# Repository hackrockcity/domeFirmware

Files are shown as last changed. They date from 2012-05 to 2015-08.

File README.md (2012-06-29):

domeFirmware
============

LED driver for the dome project. Each board can control 8 LED strips, each of which is up to 5m long.

## python_host
A python server that listens on UDP for a serialized 24bit RGB stream (8 bits per channel) that describes a 24 wide by 160 high image from top left to bottom right. (Yo dawg your aspect ratio is wrong). The data is then output to a Teensy over a high-speed serial port.

Usage:

```python
    python domelistener.py
```

## board
PCB design for the breakout board

## firmware
Firmware that should be compiled using the Makefile, then uploaded to the teensy using the teensy utility.

## mounting hardware
3d models for whatever mounts.

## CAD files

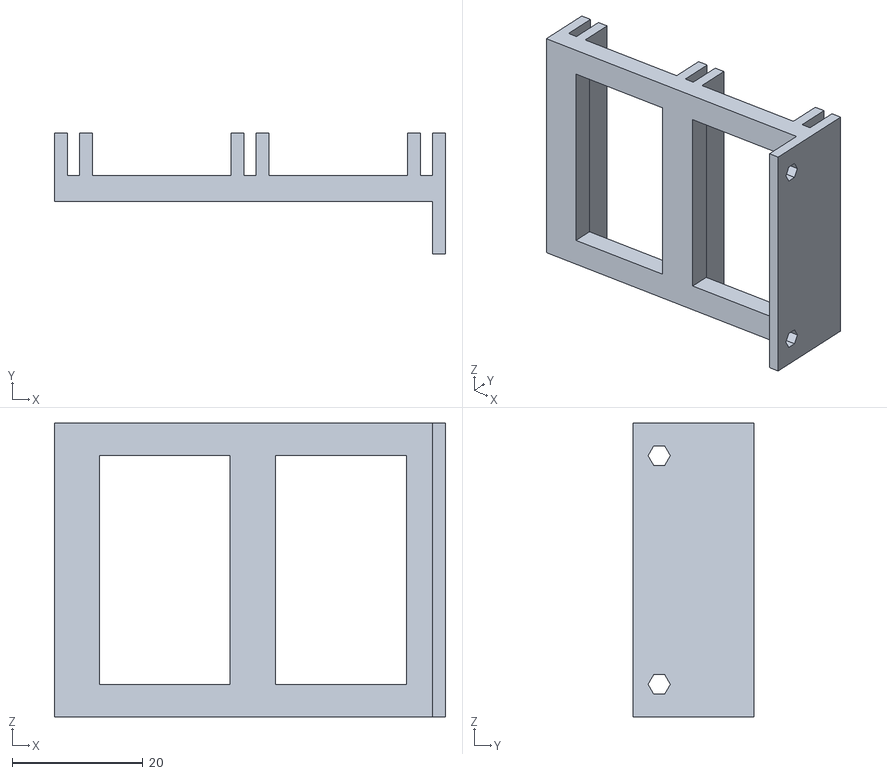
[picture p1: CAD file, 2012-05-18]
mounting hardware/mount.stl
59.9 x 18.5 x 45.0

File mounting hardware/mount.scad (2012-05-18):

board_width = 45;
board_thickness = 1.85;
board_separation = 27;

platform_thickness = 2;

module ledge() {
  union() {
    cube(size = [6.5,platform_thickness,board_width]);
    translate([0,platform_thickness+board_thickness,0])
      cube(size = [6.5,platform_thickness,board_width]);

//    translate([0,platform_thickness+1,0])
//      rotate(a=[90,0,0])
//        translate([6,3,0])
//          cylinder(h=platform_thickness+1,r=1.3);

//    translate([0,platform_thickness+1,board_width-6])
//      rotate(a=[90,0,0])
//        translate([6,3,0])
//          cylinder(h=platform_thickness+1,r=1.3);
  }
}

module mount() {
  translate([-8,0,0]) {

    difference() {
      cube(size=[8,platform_thickness,board_width]);

      translate([0,platform_thickness+.25,0])
        rotate(a=[90,0,0])
          translate([4,5,0])
            cylinder(h=platform_thickness+.5,r=1.7);

      translate([0,platform_thickness+.25,board_width-6])
        rotate(a=[90,0,0])
          translate([4,1,0])
            cylinder(h=platform_thickness+.5,r=1.7);
    }
  }
}

difference() {
  cube(size = [4,2*board_separation+platform_thickness*2+board_thickness,board_width]);
  translate([-.5,6,5])
    cube(size=[5,20,board_width-10]);
  translate([-.5,6+board_separation,5])
    cube(size=[5,20,board_width-10]);
}

mount();


translate([4,0,0])
  ledge();
translate([4,board_separation,0])
  ledge();
translate([4,board_separation*2,0])
  ledge();

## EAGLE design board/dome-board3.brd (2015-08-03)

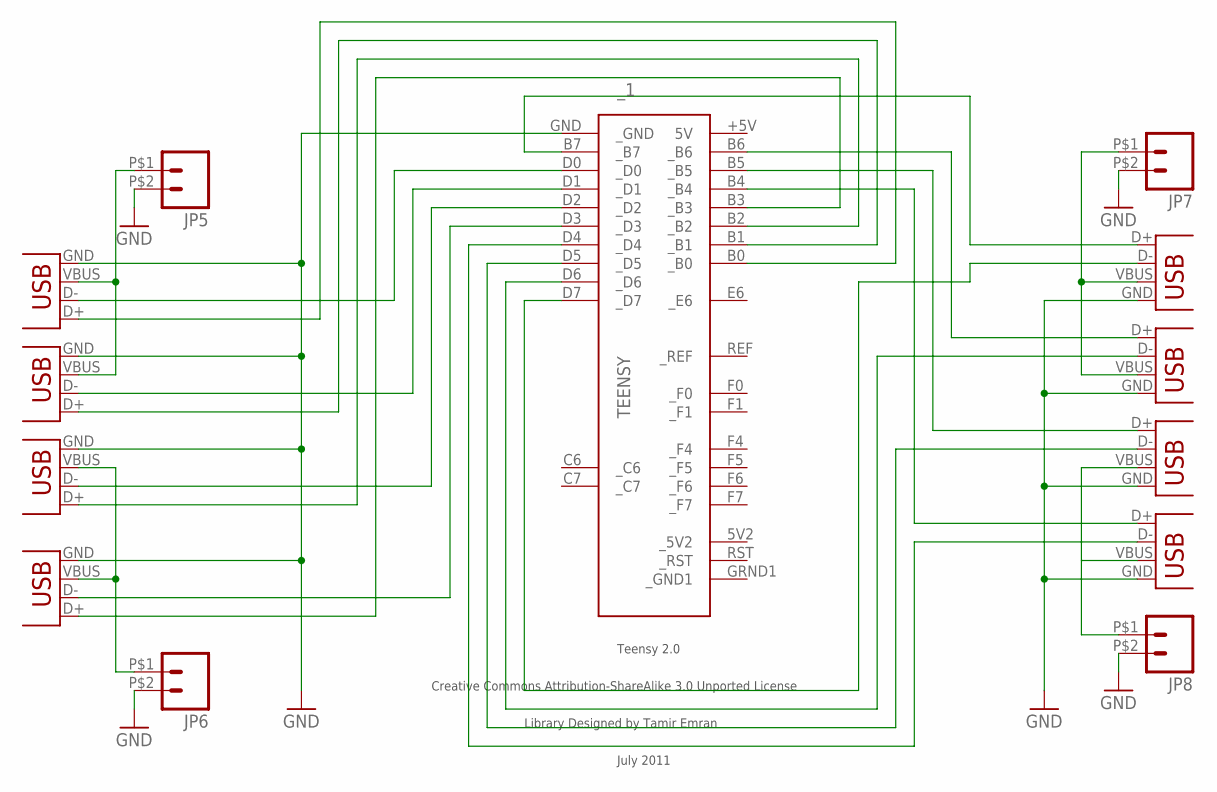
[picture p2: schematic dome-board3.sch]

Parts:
JP5, JP6, JP7, JP8: M026.35MM; SCREWTERMINAL-6.35MM-2
USB1, USB2, USB3, USB4, USB5, USB6, USB7, USB8: USB; USBA
_1: TEENSY

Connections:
GND: JP5.P$2 (2), JP6.P$2 (2), JP7.P$2 (2), JP8.P$2 (2), USB1.GND, USB2.GND, USB3.GND, USB4.GND, USB5.GND, USB6.GND, USB7.GND, USB8.GND, _1.GND (_GND)
unnamed: USB1.D+, _1.B0 (_B0)
unnamed: USB2.D+, _1.B1 (_B1)
unnamed: USB3.D+, _1.B2 (_B2)
unnamed: USB4.D+, _1.B3 (_B3)
unnamed: USB5.D+, _1.B4 (_B4)
unnamed: USB6.D+, _1.B5 (_B5)
unnamed: USB7.D+, _1.B6 (_B6)
unnamed: USB1.D-, _1.D0 (_D0)
unnamed: USB2.D-, _1.D1 (_D1)
unnamed: USB3.D-, _1.D2 (_D2)
unnamed: USB4.D-, _1.D3 (_D3)
unnamed: USB5.D-, _1.D4 (_D4)
unnamed: USB6.D-, _1.D5 (_D5)
unnamed: USB7.D-, _1.D6 (_D6)
unnamed: USB8.D-, _1.D7 (_D7)
unnamed: USB8.D+, _1.B7 (_B7)
VCC1: JP5.P$1 (1), USB1.VBUS, USB2.VBUS
VCC2: JP7.P$1 (1), USB7.VBUS, USB8.VBUS
VCC3: JP6.P$1 (1), USB3.VBUS, USB4.VBUS
VCC4: JP8.P$1 (1), USB5.VBUS, USB6.VBUS

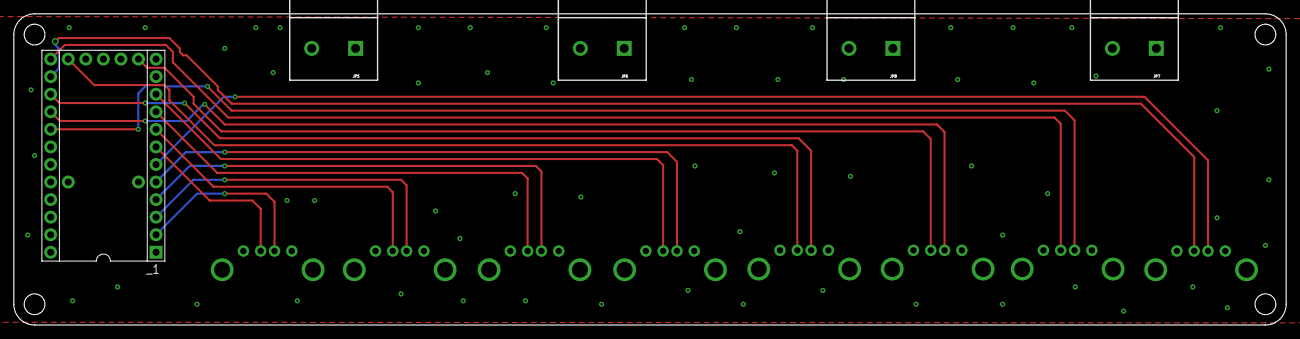
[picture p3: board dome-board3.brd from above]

Board: 2 copper layers, 184.0 x 45.0 mm, 13 parts (0 on the bottom side), 21 nets.

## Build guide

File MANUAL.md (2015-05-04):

# DomeStar Users Manual

## Introduction

This document serves as a general purpose overview for DomeStar.  It will walk through construction, the various software components and protocols, and applications that have been developed for the project.

## Setup

### Requirements

To install DomeStar you will need a somewhat recent MacBook Pro or Linux laptop with a decent amount of horse power.  You will needed the following software:

* Git
* GCC build tools
* [domeFirmware](https://github.com/hackrockcity/domeFirmware)
* [Processing](http://www.processing.org)
* [Processing UDP library](http://www.ubaa.net/shared/processing/udp/)
* [Processing OSC Library](http://www.sojamo.de/libraries/oscP5/)
* [domeTransmitter](https://github.com/hackrockcity/domeTransmitter)
* DarwiinRemoteOSC or something similar (WiiMote -> Open Sound Control)

### Components

DomeStar is made up of the following components

* 5 x Controller Boxes
* 5 x Wood Strip Mounts
* 40 x 5m LED strips
* Power Supply
* 5 x DC power cables
* USB hub
* USB extension cables
* Lot of zip ties

### Physical construction

Top of DomeStar

To build DomeStar first build a dome.  The dome should be at least 8ft in diameter, but preferably bigger.  Only 2V domes have been used, it is unknown if other configurations will work.

At the top of the dome zip tie the five controller boxes with the JST connector wires facing out from the center of the dome.  Make sure the lids of the boxes face down so they can be accessed.

At the very center of the dome zip tie the USB hub down.  Connect each box to the USB hub.  Plug a USB cable into the hub and zip tie it down the side of the dome as far as it will go.  Then connect the USB extension and continue down to the ground and to the laptop.

Zip tie the DC power cables up the same path the USB extension took and plug one cable into each box.  The connector should push in, turn and click to lock.  Some of the connectors are damaged and take some finessing, it would be worthwhile to try it on the ground before doing it on the top of a dome.

Zip tie the wood strip mounts across two poles of the dome so that they create a bridge just below the controller boxes.  Route a zip tie through each pair of slots in the mount and close but leave loose enough to guide an LED strip through.

Zip tie the LED strips around the sides of the dome, spacing them evently.  Eight strips should connect to each box.  Make sure that the strips are tied such that the strain on the JST connector is minimized.  There should be some slack at the top.  See the 
picture at the top.

Connect the DC power cables to the power supply and connect the power supply to a AC power source like a generator or the grid.

### Configuration

You should be ready to power on DomeStar and configure it.  First do a quick on and off test of the power supply as a smoke test. If something smokes, STOP and contact a DomeStar Service Technician immediately.

Once the USB cable has been connected to the notebook you should see additional USB devices show up in /dev.  Open a terminal and take a look:

```
macbook$ ls /dev/cu.*

/dev/cu.Bluetooth-Port  /dev/cu.Bluetooth-Modem /dev/cu.JustinsJAMBOX-SPPDev-1
/dev/cu.usbmodem00001   /dev/cu.usbmodem10001   /dev/cu.usbmodem20001
/dev/cu.usbmodem30001   /dev/cu.usbmodem40001
```

You should see 5 devices matching "cu.usbmodemNNNNN".  The numbers are usually but not always five digits.  These are the controler boxes.  Now go to the domeFirmware/c++_host directory and edit run_osx.sh.

```
#!/bin/bash
./host 160 40 /dev/cu.usbmodem00001 0 /dev/cu.usbmodem10001 8 /dev/cu.usbmodem20001 16 /dev/cu.usbmodem30001 24 /dev/cu.usbmodem40001 32
```

The syntax of the host program is:

```
./host [height] [width] [device] [offset]...[device] [offset]
```

For now just replace the usbmodem devices with ones that came up on your notebook if they are different.  You will need to reorder them in the next step.

Run the script to start the listener

```
./run_osx.sh
```

Now start Processing and open domeTransmitter.  You will need to make some changes to the code to get it ready for configuration.  In the main domeTransmitter.pde find the section near the top that lists all the enabled routines, comment all but TestPattern.

``` Java
public Routine[] enabledRoutines = new Routine[] {
    new TestPattern(true)
    //new Configulate(),
    //new TestPattern(false),
    //new Waves(),
    //new WarpSpeedMrSulu(),
    //new Warp(),
    //new TrialOfZod(),
    //new Seizure(),
    //new RainbowColors(),
    //new RGBRoutine(),
    //new Pong(),
    //new Greetz(),
    //new FFTDemo(),
    //new DropTheBomb(),
    //new ColorDrop(),
    //new Chase(),
    //new Bursts(),
    //new Animator("anim-nyancat",1,.5,0,0,0),
};
```

Run the Processing sketch and hopefully you should see strips turning on and off in a seemingly random order.  If so, YAY IT IS WORKING!

Now turn on the Configulate routine.

``` Java
public Routine[] enabledRoutines = new Routine[] {
    new Configulate()
    //new TestPattern(true),
    //new TestPattern(false),
    //new Waves(),
    //new WarpSpeedMrSulu(),
    //new Warp(),
    //new TrialOfZod(),
    //new Seizure(),
    //new RainbowColors(),
    //new RGBRoutine(),
    //new Pong(),
    //new Greetz(),
    //new FFTDemo(),
    //new DropTheBomb(),
    //new ColorDrop(),
    //new Chase(),
    //new Bursts(),
    //new Animator("anim-nyancat",1,.5,0,0,0),
};
```

Run the sketch again.  You should see one strip colored blue.  Use the left and right arrows to move around the dome, it should seem to go in slightly random order. Some newer strips will actually be green, they have their green and blue colors swapped.

Move around to any starting point you find reasonable.  Press space, the strip will turn light blue and another strip will turn the previous deep blue.  Move the left and right arrows until the strip to the right of the light blue one is lit.  If it's green press down to swap green and blue, press up to undo the swap.  Press space and that strip will turn light blue.  Repeat this process until you've gone through the whole dome.  

Once completed press "s" and you should see some code show up in the Processing debug console.  Copy/paste this code into the Config class replacing the STRIP_LOOKUP and SWAP_LOOKUP sections.

Now re-enable the TestPattern routine and you should see the strips going in order around the dome.

### Running DomeStar

Now that you have everything configured you can set the FRAMERATE back to 30 and comment out the TestPattern and uncomment the other modes in enabledModes.  You're ready to run DomeStar! 

You'll want to test out the WiiMote controls next.  We've used DarwiinOSC in the past, but it can be a pain to get working on newer versions of OSX. 

### Running DomeStar.us (EXPERIMENTAL)

DomeStar.us is an attempt to allow people to control DomeStar using their smartphone. It uses a web app hosted at [domestar.us](http://www.domestar.us) that takes the phone's orientation data and sends it to the dome using WebSockets.  If DomeStar and the phone are on the same WiFi network it will do this using a direct connection, otherwise it will send via a proxy on domestar.us.

   

There are four "totems" that need to be placed in the dome at about eye level.  The totems are a rocket, a beer mug, a squirrel and a globe.  These allow the user to calibrate their phone so that its orientation data lines up with the dome.  Each totem should be placed 90 degrees from the previous one so that the "north", "south", "east" and "west" points in the dome are covered.  These points don't need to coordinate with actual north, south, east or west.  The order of the totems should be: rocket, beer, squirrel, and then globe.

To run DomeStar in this mode, first get [DomeWebProxy](https://github.com/hackrockcity/DomeWebProxy).  Edit the Config class and paste in the appropriate STRIP_LOOKUP and SWAP_LOOKUP lines from domeTransmitter.  Run the sketch and it should connect to the domestar.us website.  If you see lots of connection errors in the Processing error console, contact Justin and have him restart the domestar proxy.

Now connect to domestar.us website using your smartphone.  Go through the calibration  routine, pointing at each totem and pressing the button.  Then tap a color swatch and use your phone like a brush.  The part of the dome you're pointing at *should* light up.

### Creating your own Routines

If you're ready to start making your own DomeStar routines go and grab [BlinkeyDomeSimulator](https://github.com/hackrockcity/BlinkeyDomeSimulator).  This sketch is a virtual version of DomeStar.  Run it and then run domeTransmitter and you should see the routines on the virtual DomeStar.  Now add a new class to domeTransmitter.

``` Java
class MyRoutine extends Routine {
  
  public MyRoutine() {
  }
  
  void draw() {
    draw.background(primaryColor);
  }
}
```

The D-Pad on the WiiMote changes the value of primaryColor, secondaryColor and teriaryColor so you should try to incorporate those into your routine.  You can also use the controller object to get the accelerometer data from the WiiMote.  Look at routines like TrialOfZod to get an idea of how that works.  Add your routine to the enabledRoutines array and run it.

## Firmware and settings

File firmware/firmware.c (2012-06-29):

/* Simple example for Teensy USB Development Board
 * http://www.pjrc.com/teensy/
 * Copyright (c) 2008 PJRC.COM, LLC
 * 
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
 * THE SOFTWARE IS PROVIDED "AS IS", WITHOUT WARRANTY OF ANY KIND, EXPRESS OR
 * IMPLIED, INCLUDING BUT NOT LIMITED TO THE WARRANTIES OF MERCHANTABILITY,
 * FITNESS FOR A PARTICULAR PURPOSE AND NONINFRINGEMENT. IN NO EVENT SHALL THE
 * AUTHORS OR COPYRIGHT HOLDERS BE LIABLE FOR ANY CLAIM, DAMAGES OR OTHER
 * LIABILITY, WHETHER IN AN ACTION OF CONTRACT, TORT OR OTHERWISE, ARISING FROM,
 * OUT OF OR IN CONNECTION WITH THE SOFTWARE OR THE USE OR OTHER DEALINGS IN
 * THE SOFTWARE.
 */

#include <avr/io.h>
#include <avr/pgmspace.h>
#include <avr/interrupt.h>
#include <stdint.h>
#include <util/delay.h>
#include "usb_serial.h"

#define LED_CONFIG	(DDRD |= (1<<6))
#define LED_ON		(PORTD |= (1<<6))
#define LED_OFF		(PORTD &= ~(1<<6))
#define CPU_PRESCALE(n) (CLKPR = 0x80, CLKPR = (n))

void send_str(const char *s);
uint8_t recv_str(char *buf, uint8_t size);
void parse_and_execute_command(const char *buf, uint8_t num);

// Serial to parallel SPI driver
static
void send_parallel_byte(
	const uint8_t c
)
{
	PORTD = 0x00;

	PORTB = c;

	PORTD = 0xFF;
}

int main(void)
{
	CPU_PRESCALE(0);
	usb_init();

	DDRB = 0xFF;
	DDRD = 0xFF;	

	while (1)
	{
		const int8_t n = usb_serial_available();
		if (n <= 0)
			continue;

		const uint8_t irq_flags = SREG;
		cli();

		int8_t i;
		for (i = 0 ; i < n ; i++)
		{
#define CDC_RX_ENDPOINT		3
			UENUM = CDC_RX_ENDPOINT;
			const uint8_t c = UEDATX;
			send_parallel_byte(c);
		}

		// Release the USB buffer
		UEINTX = 0x6B;

		// Re-enabled interrupts
		SREG = irq_flags;
	}
}

// Send a string to the USB serial port.  The string must be in
// flash memory, using PSTR
//
void send_str(const char *s)
{
	char c;
	while (1) {
		c = pgm_read_byte(s++);
		if (!c) break;
		usb_serial_putchar(c);
	}
}

// Receive a string from the USB serial port.  The string is stored
// in the buffer and this function will not exceed the buffer size.
// A carriage return or newline completes the string, and is not
// stored into the buffer.
// The return value is the number of characters received, or 255 if
// the virtual serial connection was closed while waiting.
//
uint8_t recv_str(char *buf, uint8_t size)
{
	int16_t r;
	uint8_t count=0;

	while (count < size) {
		r = usb_serial_getchar();
		if (r != -1) {
			if (r == '\r' || r == '\n') return count;
			if (r >= ' ' && r <= '~') {
				*buf++ = r;
				usb_serial_putchar(r);
				count++;
			}
		} else {
			if (!usb_configured() ||
			  !(usb_serial_get_control() & USB_SERIAL_DTR)) {
				// user no longer connected
				return 255;
			}
			// just a normal timeout, keep waiting
		}
	}
	return count;
}

// parse a user command and execute it, or print an error message
//
void parse_and_execute_command(const char *buf, uint8_t num)
{
	uint8_t port, pin, val;

	if (num < 3) {
		send_str(PSTR("unrecognized format, 3 chars min req'd\r\n"));
		return;
	}
	// first character is the port letter
	if (buf[0] >= 'A' && buf[0] <= 'F') {
		port = buf[0] - 'A';
	} else if (buf[0] >= 'a' && buf[0] <= 'f') {
		port = buf[0] - 'a';
	} else {
		send_str(PSTR("Unknown port \""));
		usb_serial_putchar(buf[0]);
		send_str(PSTR("\", must be A - F\r\n"));
		return;
	}
	// second character is the pin number
	if (buf[1] >= '0' && buf[1] <= '7') {
		pin = buf[1] - '0';
	} else {
		send_str(PSTR("Unknown pin \""));
		usb_serial_putchar(buf[0]);
		send_str(PSTR("\", must be 0 to 7\r\n"));
		return;
	}
	// if the third character is a question mark, read the pin
	if (buf[2] == '?') {
		// make the pin an input
		*(uint8_t *)(0x21 + port * 3) &= ~(1 << pin);
		// read the pin
		val = *(uint8_t *)(0x20 + port * 3) & (1 << pin);
		usb_serial_putchar(val ? '1' : '0');
		send_str(PSTR("\r\n"));
		return;
	}
	// if the third character is an equals sign, write the pin
	if (num >= 4 && buf[2] == '=') {
		if (buf[3] == '0') {
			// make the pin an output
			*(uint8_t *)(0x21 + port * 3) |= (1 << pin);
			// drive it low
			*(uint8_t *)(0x22 + port * 3) &= ~(1 << pin);
			return;
		} else if (buf[3] == '1') {
			// make the pin an output
			*(uint8_t *)(0x21 + port * 3) |= (1 << pin);
			// drive it high
			*(uint8_t *)(0x22 + port * 3) |= (1 << pin);
			return;
		} else {
			send_str(PSTR("Unknown value \""));
			usb_serial_putchar(buf[3]);
			send_str(PSTR("\", must be 0 or 1\r\n"));
			return;
		}
	}
	// otherwise, error message
	send_str(PSTR("Unknown command \""));
	usb_serial_putchar(buf[0]);
	send_str(PSTR("\", must be ? or =\r\n"));
}

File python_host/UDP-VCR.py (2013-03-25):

import socket
import time
import sys
import Queue
import multiprocessing
import LedStrips

# UDP settings
host = "0.0.0.0"
port = 58082
buffer_size = 19201

# Image settings
image_height = 160
image_width = 40

frameSize = (image_width * image_height * 3) + 1

class Recorder:

	recFile = None
	recordedFrames = 0
	lastReceived = time.time()
	timeout = 6
	recording = False
	avgFrameRate = 0

	def __init__(self, sock):
		
		self.sock = sock

		# Open the data file
		self.recFile = open("recfile.dat", "w")

	def record(self):

		# Set socket to blocking, one second timeout
		self.sock.setblocking(1)
		self.sock.settimeout(1)
		
		self.recording = True

		frame_time = time.time()
		total_time = time.time()

		while self.recording == True:

			try:
				
				# Receive the data from the socket
				data, addr = sock.recvfrom(buffer_size)

				self.lastReceived = time.time()

				# If the data is valid, write the data to the recording file
				if self.process_data(data):
					self.write_frame(data)
					self.recordedFrames += 1

				# Every 30 frames, output framerate data
				if self.recordedFrames % 30 == 0:
					frame_rate = 30 / (time.time() - frame_time)
					frame_time = time.time()
					self.avgFrameRate = (self.avgFrameRate + frame_rate) / 2

			except socket.timeout:
				# Stopped receiving UDP data, get ready to stop the recorder
				print "Timed out waiting for UDP data. Last received %s seconds ago." % int(time.time() - self.lastReceived)

				if time.time() - self.lastReceived > self.timeout:
					self.stop()

		return self.avgFrameRate
				
	def process_data(self, data):
		if not data:
			print "no data."
			return

		if data[0] != '\x01':
			print "bad header, expected=%i, got=%i"%(1, ord(data[0]))
			return

		expected_length = image_width*image_height*3+1
		if len(data) != expected_length:
			print "bad data length, expected %i, got %i"%(expected_length, len(data))
			return

		return True

	def write_frame(self, data):
		self.recFile.write(data)
		
	def stop(self):
		self.recFile.close()
		self.recording = False

		print "Stopped recording after %i frames." % self.recordedFrames


class Playback:

	playFile = None
	data = None
	numFrames = None
	currentFrame = 0
	frameRate = 0
	loops = 1
	loopNum = 0

	strips = []

	blinkyboards = [
		['/dev/cu.usbmodem66661', 0]
	]	

	new_data_event = multiprocessing.Event()
	draw_event = multiprocessing.Event()
	image_data = multiprocessing.Array('c', image_width*image_height*3)

	# Initiate a player with the playback framerate and the number of loops to do
	# Set loops to -1 for infinite playback
	def __init__(self, avgFrameRate, loops):
		# Open the recorded file
		self.playFile = open("recfile.dat", "r")

		# Load the recorded frames into RAM and close the file.
		# This will take a lot of RAM. About 500kb per second.
		self.data = self.playFile.read()
		self.playFile.close()

		self.numFrames = (len(self.data) / frameSize)

		self.frameRate = avgFrameRate
		self.loops = loops

		# print "Loaded %i frames" % self.numFrames

		# Spawn a new thread for every BB8 listed in blinkyboards[]
		for blinkyboard in self.blinkyboards:
			strip = threadedLedStrips(blinkyboard[0], blinkyboard[1],
				self.image_data, self.new_data_event, self.draw_event)
			strip.start()
			self.strips.append(strip)

		time.sleep(.5)

	def play(self):

		# Die if no frames recorded
		if self.numFrames == 0:
			self.stop()
			return

		self.playing = True
		frame_time = time.time()

		while self.playing == True:
			# Grab the current frame of data from the huge heap of data loaded from the file
			startByte = self.currentFrame * frameSize
			endByte = startByte + frameSize
			idata = self.data[startByte : endByte]
			
			start_time = time.time()
			#send_draw_start_time = time.time()
			
			# Clock out the previous frame
			self.new_data_event.clear()
			self.draw_event.set()
			#send_draw_time = time.time() - send_draw_start_time

			# Load in the next frame
			load_frame_start_time = time.time()
			self.image_data[:] = idata[1:]

			load_frame_time = time.time() - load_frame_start_time

		#	print "Send data--"
			send_data_start_time = time.time()
			self.draw_event.clear()
			self.new_data_event.set()
			send_data_time = time.time() - send_data_start_time

			# Print current loop and frame position, along with frame rate
			if self.currentFrame % 30 == 0:
				frame_rate = self.currentFrame / (time.time() - frame_time)
				print "\tLoop: %i Frame: %i Frame rate: %.2f" % (self.loopNum, self.currentFrame, frame_rate)

			# Insert an appropriate delay so that the output frame rate tracks the avg requested frame rate
			if time.time() - start_time < (1.0 / self.frameRate):
				time.sleep((1.0 / self.frameRate) - (time.time() - start_time))

			self.currentFrame +=1

			# We've played all of the available frames!
			if self.currentFrame >= self.numFrames:
				self.end()

	def end(self):
		if self.loopNum == self.loops:
			self.stop()
		else:
			self.loopNum += 1
			self.currentFrame = 0

	def stop(self):
		# Terminate the playback!
		self.playing = False
		for strip in self.strips:
			strip.terminate()

		print "Stopped playing after %i loops of %i/%i frames" % (self.loops, self.currentFrame, self.numFrames)


class threadedLedStrips(multiprocessing.Process):

	def __init__(self, port_name, offset,
			data_array, new_data_event, draw_event):
		self.port_name = port_name
		self.offset = offset

		self.strip = LedStrips.LedStrips(image_width, offset)
		self.strip.connect(port_name)

		self.data = data_array
		self.new_data_event = new_data_event
		self.draw_event = draw_event

		multiprocessing.Process.__init__(self, target=self.run)

	def run(self):
		while True:
			# Wait for new_data_event semaphore
			self.new_data_event.wait()

			# Load data into strip
			self.strip.load_data(self.data)

			# Wait for draw_event semaphore
			self.draw_event.wait()
			
			# Clock out the flip bits (0x00)
			self.strip.flip()

if __name__ == "__main__":

	avgFrameRate = 30

	if len(sys.argv) > 1 and sys.argv[1] == "-r":
		sock = socket.socket(socket.AF_INET, socket.SOCK_DGRAM)
		sock.bind((host,port))

		# Start the recording
		recorder = Recorder(sock)
		avgFrameRate = recorder.record()

	# Recording is over, start playback
	player = Playback(avgFrameRate, -1)
	while True:
		player.play()

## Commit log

2012-04-29 adding teensy firmware and dependencies
2012-05-01 initial driver boards
    [dome-board.brd, dome-board.sch]
2012-05-01 adding dome-board 2 and 3
    [dome-board2.brd, dome-board2.sch, dome-board3.brd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]
2012-05-02 updated dome-board3
    [dome-board3.brd, dome-board3.sch]
2012-05-02 Re-organize files.
    [dome-board.brd, dome-board.sch, dome-board2.brd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]
2012-05-03 updated circuit board
    [dome-board3.brd, dome-board3.sch]
2012-05-03 adding enclosures file
2012-05-08 final board
    [dome-board3.brd, dome-board3.sch]
2012-05-12 FIX ALL THE ERRORS
    [LedStrips.py, domelistener.py]
2012-05-12 Drop frames so as not to fall behind.
2012-05-18 Add board standoff model
    [mount.scad, mount.stl]
2012-05-18 Make udp listener fast, still need to fix data formatter.
    [LedStrips.py, domelistener.py, test_LedStrips.py]
2012-05-25 Add coreldraw file for the bar mounts
2012-06-29 Add threading; each strip gets updated in its own pthread. This is somehow more jittery than the round-robin version, perhaps devices are blocking.
2012-06-29 nonworking threading (segfault)
2015-08-02 Domestar lives again???
    [dome-board4.brd, dome-board4.sch]
2015-08-03 Dome board Rev4
    [dome-board3.brd, dome-board3.sch, dome-board4.sch]
2015-08-03 New board, as ordered

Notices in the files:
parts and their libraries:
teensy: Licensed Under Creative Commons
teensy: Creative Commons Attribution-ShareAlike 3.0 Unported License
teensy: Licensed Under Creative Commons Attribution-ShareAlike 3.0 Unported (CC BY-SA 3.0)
